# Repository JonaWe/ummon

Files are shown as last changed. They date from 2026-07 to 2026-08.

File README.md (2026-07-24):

# ummon

ummon (from German *Umgebungsmonitor*, "environment monitor") is an ESP32-C6 based environmental sensor board with USB-C power. It reads several environmental sensors over I²C and drives an e-paper display (a 7.5" Waveshare panel in this build). The board is a custom 4-layer PCB designed in KiCad, powered from USB-C with on-board 3.3 V regulation.

## Features

- MCU: ESP32-C6-WROOM-1 (Wi-Fi 6, Bluetooth LE, Zigbee/Thread)
- Sensors over I²C:
  - SHT41 for temperature and humidity
  - SCD41 for CO₂
  - SGP41 for VOC / air quality
- Display: e-paper via an on-board boost converter for the panel supply rails (7.5" Waveshare V2 used here)
- Power: USB-C input, AMS1117 3.3 V LDO, TVS/ESD protection on VBUS and the USB data lines

## Repository structure

```
├── hardware/      KiCad project (schematic, PCB, footprints, datasheets)
├── firmware/      ESP32-C6 firmware (planned)
└── mechanical/    3D-printed enclosure (planned)
```

## Hardware

The PCB uses a 4-layer stackup:

| Layer | Purpose |
|---|---|
| Top | Signals + components |
| Inner 1 | Continuous GND plane |
| Inner 2 | 3.3 V plane |
| Bottom  | Signals |

## Status

- [x] Schematic
- [x] PCB layout
- [ ] Firmware
- [ ] Enclosure

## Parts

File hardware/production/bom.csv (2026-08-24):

Designator | Footprint | Quantity | Value | LCSC Part #
C1, C10, C12, C13, C15, C16, C19, C20, C21, C5, C6, C7, C8 | 0805 | 13 | 100nF | C49678
C14, C17, C18 | 1206 | 3 | 22µF | C12891
C2, C3, C40 | 0805 | 3 | 1µF | C28323
C22 | 1206 | 1 | 4.7μF | C29823
C24, C28, C30, C34, C36 | 0805 | 5 | 1μF/25V | C28323
C26 | 1206 | 1 | 4.7μF/50V | C29823
C27 | 0805 | 1 | 1μF/10V | C28323
C32, C38 | 0805 | 2 | 1μF/50V | C28323
C4, C9 | 0805 | 2 | 10µF | C440198
D2, D3, D4 | SOD-123_L2.8-W1.8-LS3.7-RD | 3 | MBR0530 | C18863
D5 | SOD-123F_L2.8-W1.8-LS3.7-RD | 1 | SMF5.0A | C169426
D6 | SOT-23-6_L2.9-W1.6-P0.95-LS2.8-BL | 1 | USBLC6-2SC6 | C7519
F1 | F1206 | 1 | 1A/24V | C7542957
LED1 | LED-SMD_L1.6-W0.8-R-RD | 1 | KT-0603R | C2286
LED2, LED3 | LED0805-R-RD | 2 | 0805G | C2297
P1 | FPC-SMD_AFC11-S24ICC-00 | 1 | Display | C11075
Q1 | SOT-23-3_L2.9-W1.6-P1.90-LS2.8-BR | 1 | BSS138LT1G | C82045
Q2, Q3 | SOT-23_L2.9-W1.3-P1.90-LS2.4-BR | 2 | AO3401A | C15127
R1 | 0805 | 1 | 4.7Ω | C17675
R10 | 0805 | 1 | 2.2Ω | C17521
R11, R13, R16 | 0805 | 3 | 1Ω | C25271
R12, R15 | 0805 | 2 | 220Ω | C17557
R14 | 0805 | 1 | 1kΩ | C17513
R17, R19 | 0805 | 2 | 100kΩ | C149504
R18, R6, R7 | 0805 | 3 | 4.7kΩ | C17673
R2, R3 | 0805 | 2 | 5.1kΩ | C27834
R4, R5, R8, R9 | 0805 | 4 | 10kΩ | C17414
SW1 | SW-SMD_L3.9-W3.0-P4.45 | 1 | Reboot | C720477
SW2 | SW-SMD_L3.9-W3.0-P4.45 | 1 | Flash | C720477
SW3 | SW-SMD_L3.9-W3.0-P4.45 | 1 | Test Button | C720477
SW4 | SW-SMD_MSK12CO2 | 1 | MINI MSK12CO2 | C2681570
U1 | ESP32-C6-WROOM-1 | 1 | ESP32-C6-WROOM-1-N8 | C5366877
U2 | LGA-20_L10.1-W10.1-P1.25-TL | 1 | SCD41 | C3659294
U3 | DFN-6_L2.4-W2.4-P0.80-TL-EP | 1 | SGP41 | C3659325
U4 | DFN-4_L1.5-W1.5-SHT41-AD1B-R2 | 1 | SHT41 | C7461861
U5 | SOT-223-3_L6.5-W3.4-P2.30-LS7.0-BR | 1 | AMS1117-3.3 | C6186
U6 | IND-SMD_L4.5-W4.0 | 1 | 10μH | C2929419
USB1 | USB-C-SMD_TYPE-C-16PIN-2MD-073 | 1 | TYPE-C 16PIN 2MD | C2765186

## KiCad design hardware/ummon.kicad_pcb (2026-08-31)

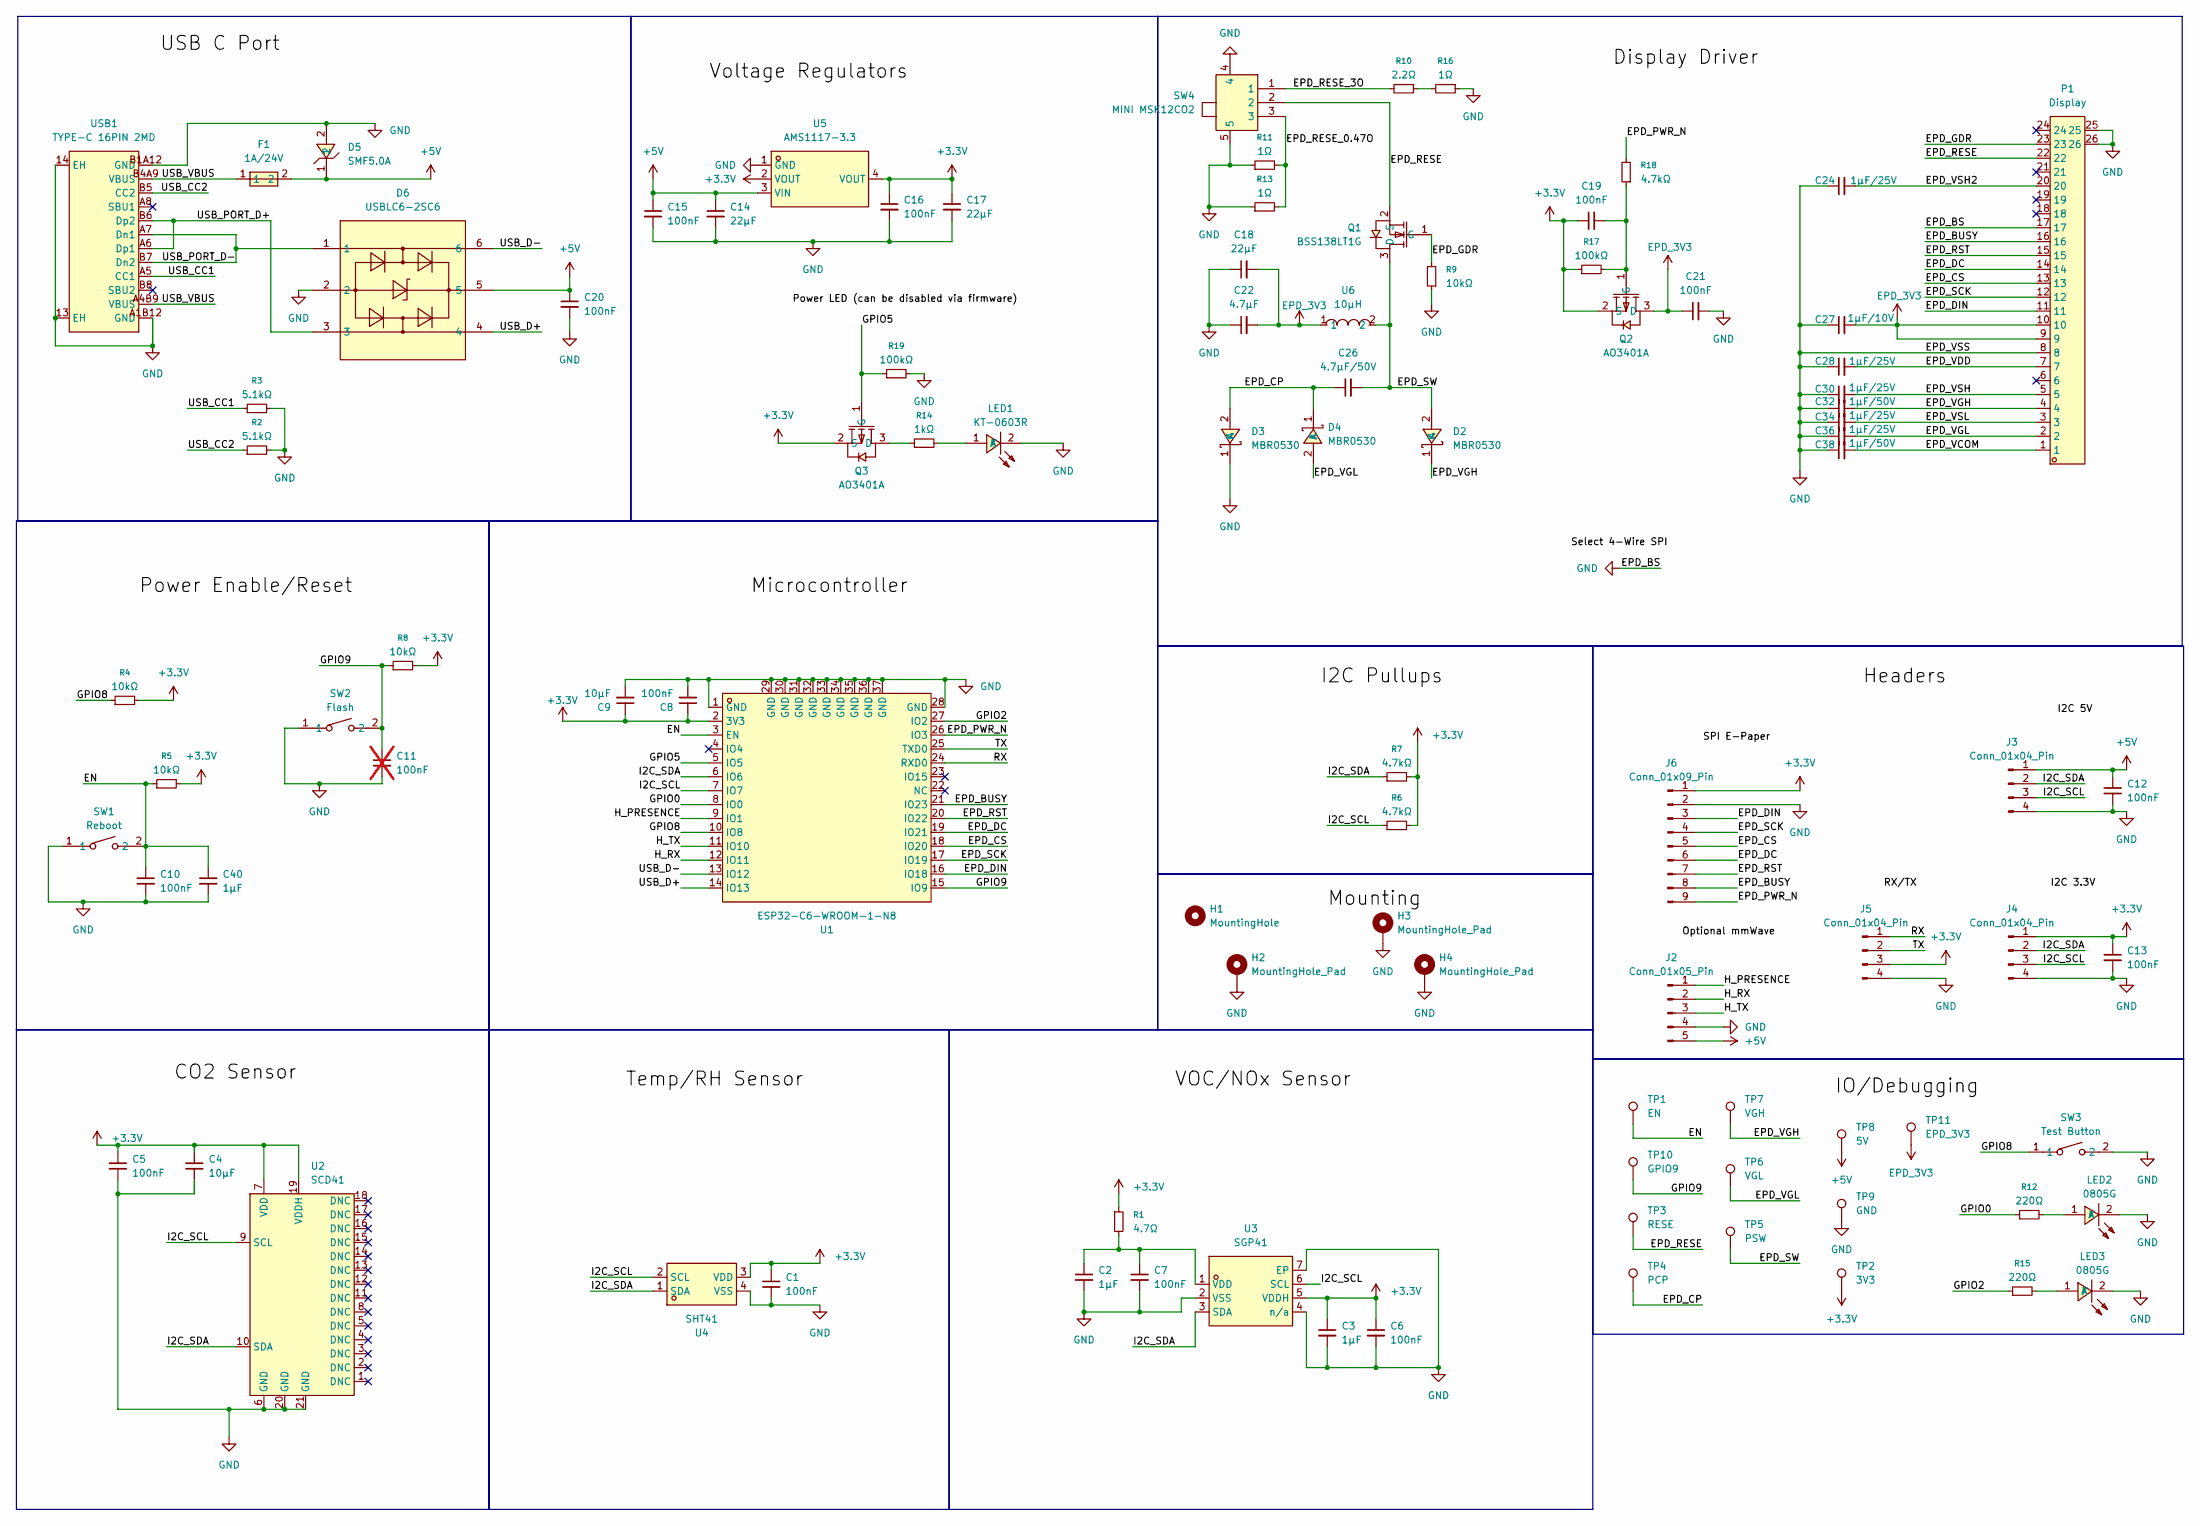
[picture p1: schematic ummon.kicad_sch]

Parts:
C1, C5, C6, C7, C8, C10, C12, C13, C15, C16, C19, C20, C21: 100nF; C_0805_2012Metric; LCSC Part C49678
C2, C3, C40: 1µF; C_0805_2012Metric; LCSC Part C28323
C4, C9: 10µF; C_0805_2012Metric; LCSC Part C440198
C11: 100nF; C_0805_2012Metric; LCSC Part C49678; not fitted
C14, C17, C18: 22µF; C_1206_3216Metric; LCSC Part C12891
C22: 4.7μF; C_1206_3216Metric; LCSC Part C29823
C24, C28, C30, C34, C36: 1μF/25V; C_0805_2012Metric; LCSC Part C28323
C26: 4.7μF/50V; C_1206_3216Metric; LCSC Part C29823
C27: 1μF/10V; C_0805_2012Metric; LCSC Part C28323
C32, C38: 1μF/50V; C_0805_2012Metric; LCSC Part C28323
D2, D3, D4: MBR0530; SOD-123_L2.8-W1.8-LS3.7-RD; MPN LMBR0530T1G; LCSC Part C18863
D5: SMF5.0A; SOD-123F_L2.8-W1.8-LS3.7-RD; MPN SMF5.0A; LCSC Part C169426
D6: USBLC6-2SC6; SOT-23-6_L2.9-W1.6-P0.95-LS2.8-BL; MPN USBLC6-2SC6; LCSC Part C7519
F1: 1A/24V; F1206; MPN 1206L100/24NR; LCSC Part C7542957
H1: MountingHole; MountingHole_3.2mm_M3
H2, H3, H4: MountingHole_Pad; MountingHole_3.2mm_M3_Pad
J2: Conn_01x05_Pin; PinHeader_1x05_P2.54mm_Vertical; LCSC Part C492404
J3, J4, J5: Conn_01x04_Pin; PinHeader_1x04_P2.54mm_Vertical; LCSC Part C2691448
J6: Conn_01x09_Pin; PinHeader_1x09_P2.54mm_Vertical
LED1: KT-0603R; LED-SMD_L1.6-W0.8-R-RD; MPN KT-0603R; LCSC Part C2286
LED2, LED3: 0805G; LED0805-R-RD; MPN KT-0805G; LCSC Part C2297
P1: Display; FPC-SMD_AFC11-S24ICC-00; MPN AFC11-S24ICC-00; LCSC Part C11075
Q1: BSS138LT1G; SOT-23-3_L2.9-W1.6-P1.90-LS2.8-BR; MPN BSS138LT1G; LCSC Part C82045
Q2, Q3: AO3401A; SOT-23_L2.9-W1.3-P1.90-LS2.4-BR; MPN AO3401A; LCSC Part C15127
R1: 4.7Ω; R_0805_2012Metric; LCSC Part C17675
R2, R3: 5.1kΩ; R_0805_2012Metric; LCSC Part C27834
R4, R5, R8, R9: 10kΩ; R_0805_2012Metric; LCSC Part C17414
R6, R7, R18: 4.7kΩ; R_0805_2012Metric; LCSC Part C17673
R10: 2.2Ω; R_0805_2012Metric; LCSC Part C17521
R11, R13, R16: 1Ω; R_0805_2012Metric; LCSC Part C25271
R12, R15: 220Ω; R_0805_2012Metric; LCSC Part C17557
R14: 1kΩ; R_0805_2012Metric; LCSC Part C17513
R17, R19: 100kΩ; R_0805_2012Metric; LCSC Part C149504
SW1: Reboot; SW-SMD_L3.9-W3.0-P4.45; MPN TS-1088-AR02016; LCSC Part C720477
SW2: Flash; SW-SMD_L3.9-W3.0-P4.45; MPN TS-1088-AR02016; LCSC Part C720477
SW3: Test Button; SW-SMD_L3.9-W3.0-P4.45; MPN TS-1088-AR02016; LCSC Part C720477
SW4: MINI MSK12CO2; SW-SMD_MSK12CO2; MPN MINI MSK12CO2; LCSC Part C2681570
TP1: EN; TestPoint_Pad_D1.0mm
TP2: 3V3; TestPoint_Pad_D1.0mm
TP3: RESE; TestPoint_Pad_D1.0mm
TP4: PCP; TestPoint_Pad_D1.0mm
TP5: PSW; TestPoint_Pad_D1.0mm
TP6: VGL; TestPoint_Pad_D1.0mm
TP7: VGH; TestPoint_Pad_D1.0mm
TP8: 5V; TestPoint_Pad_D1.0mm
TP9: GND; TestPoint_Pad_D1.0mm
TP10: GPIO9; TestPoint_Pad_D1.0mm
TP11: EPD_3V3; TestPoint_Pad_D1.0mm
U1: ESP32-C6-WROOM-1-N8; ESP32-C6-WROOM-1; MPN ESP32-C6-WROOM-1-N8; LCSC Part C5366877
U2: SCD41; LGA-20_L10.1-W10.1-P1.25-TL; MPN SCD41-D-R2; LCSC Part C3659294
U3: SGP41; DFN-6_L2.4-W2.4-P0.80-TL-EP; MPN SGP41-D-R4; LCSC Part C3659325
U4: SHT41; DFN-4_L1.5-W1.5-SHT41-AD1B-R2; MPN SHT41-AD1B-R2; LCSC Part C7461861
U5: AMS1117-3.3; SOT-223-3_L6.5-W3.4-P2.30-LS7.0-BR; MPN AMS1117-3.3; LCSC Part C6186
U6: 10μH; IND-SMD_L4.5-W4.0; MPN CY43-10UH; LCSC Part C2929419
USB1: TYPE-C 16PIN 2MD; USB-C-SMD_TYPE-C-16PIN-2MD-073; MPN TYPE-C 16PIN 2MD(073); LCSC Part C2765186

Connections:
+3.3V: C1.1, C3.1, C4.1, C5.1, C6.1, C8.1, C9.1, C13.1, C16.1, C17.1, C19.1, J4.1, J5.3, J6.1, Q2.2 (S), Q3.2 (S), R1.1, R4.2, R5.2, R6.2, R7.2, R8.2, R17.1, TP2.1 (1_1), U1.2 (3V3), U2.7 (VDD), U2.19 (VDDH), U3.5 (VDDH), U4.3 (VDD), U5.2 (VOUT), U5.4 (VOUT)
+5V: C12.1, C14.1, C15.1, C20.1, D5.1, D6.5, F1.2, J2.5, J3.1, TP8.1 (1_1), U5.3 (VIN)
/EN: C10.1, C40.1, R5.1, SW1.2, TP1.1 (1_1), U1.3 (EN)
/EPD_BUSY: J6.8, P1.16, U1.21 (IO23)
/EPD_CP: C26.1, D3.2 (A), D4.1 (K), TP4.1 (1_1)
/EPD_CS: J6.5, P1.13, U1.18 (IO20)
/EPD_DC: J6.6, P1.14, U1.19 (IO21)
/EPD_DIN: J6.3, P1.11, U1.16 (IO18)
/EPD_GDR: P1.23, Q1.1 (G), R9.2
/EPD_PWR_N: J6.9, R18.2, U1.26 (IO3)
/EPD_RESE: P1.22, Q1.2 (S), SW4.2, TP3.1 (1_1)
/EPD_RESE_0.47O: R11.2, R13.2, SW4.3
/EPD_RESE_3O: R10.2, SW4.1
/EPD_RST: J6.7, P1.15, U1.20 (IO22)
/EPD_SCK: J6.4, P1.12, U1.17 (IO19)
/EPD_SW: C26.2, D2.2 (A), Q1.3 (D), TP5.1 (1_1), U6.2
/EPD_VCOM: C38.2, P1.1
/EPD_VDD: C28.2, P1.7
/EPD_VGH: C32.2, D2.1 (K), P1.4, TP7.1 (1_1)
/EPD_VGL: C36.2, D4.2 (A), P1.2, TP6.1 (1_1)
/EPD_VSH: C30.2, P1.5
/EPD_VSH2: C24.2, P1.20
/EPD_VSL: C34.2, P1.3
/GPIO0: R12.1, U1.8 (IO0)
/GPIO2: R15.1, U1.27 (IO2)
/GPIO5: Q3.1 (G), R19.1, U1.5 (IO5)
/GPIO8: R4.1, SW3.1, U1.10 (IO8)
/GPIO9: C11.1, R8.1, SW2.2, TP10.1 (1_1), U1.15 (IO9)
/H_PRESENCE: J2.1, U1.9 (IO1)
/H_RX: J2.2, U1.12 (IO11)
/H_TX: J2.3, U1.11 (IO10)
/I2C_SCL: J3.3, J4.3, R6.1, U1.7 (IO7), U2.9 (SCL), U3.6 (SCL), U4.2 (SCL)
/I2C_SDA: J3.2, J4.2, R7.1, U1.6 (IO6), U2.10 (SDA), U3.3 (SDA), U4.1 (SDA)
/RX: J5.1, U1.24 (RXD0)
/TX: J5.2, U1.25 (TXD0)
/USB_CC1: R3.1, USB1.A5 (CC1)
/USB_CC2: R2.1, USB1.B5 (CC2)
/USB_D+: D6.4, U1.14 (IO13)
/USB_D-: D6.6, U1.13 (IO12)
/USB_PORT_D+: D6.3, USB1.A6 (Dp1), USB1.B6 (Dp2)
/USB_PORT_D-: D6.1, USB1.A7 (Dn1), USB1.B7 (Dn2)
/USB_VBUS: F1.1, USB1.A4B9 (VBUS), USB1.B4A9 (VBUS)
EPD_3V3: C18.2, C21.1, C22.2, C27.2, P1.9, P1.10, Q2.3 (D), TP11.1 (1_1), U6.1
GND: C1.2, C2.2, C3.2, C4.2, C5.2, C6.2, C7.2, C8.2, C9.2, C10.2, C11.2, C12.2, C13.2, C14.2, C15.2, C16.2, C17.2, C18.1, C20.2, C21.2, C22.1, C24.1, C27.1, C28.1, C30.1, C32.1, C34.1, C36.1, C38.1, C40.2, D3.1 (K), D5.2, D6.2, H2.1 (1_1), H3.1 (1_1), H4.1 (1_1), J2.4, J3.4, J4.4, J5.4, J6.2, LED1.2 (K), LED2.2 (K), LED3.2 (K), P1.8, P1.17, P1.25, P1.26, R2.2, R3.2, R9.1, R11.1, R13.1, R16.1, R19.2, SW1.1, SW2.1, SW3.2, SW4.4, SW4.5, TP9.1 (1_1), U1.1 (GND), U1.28 (GND), U1.29 (GND), U1.30 (GND), U1.31 (GND), U1.32 (GND), U1.33 (GND), U1.34 (GND), U1.35 (GND), U1.36 (GND), U1.37 (GND), U2.6 (GND), U2.20 (GND), U2.21 (GND), U3.2 (VSS), U3.4 (n/a), U3.7 (EP), U4.4 (VSS), U5.1 (GND), USB1.13 (EH), USB1.14 (EH), USB1.A1B12 (GND), USB1.B1A12 (GND)
unnamed: LED1.1 (A), R14.2
unnamed: LED2.1 (A), R12.2
unnamed: LED3.1 (A), R15.2
unnamed: C19.2, Q2.1 (G), R17.2, R18.1
unnamed: Q3.3 (D), R14.1
unnamed: R10.1, R16.2
unnamed: C2.1, C7.1, R1.2, U3.1 (VDD)

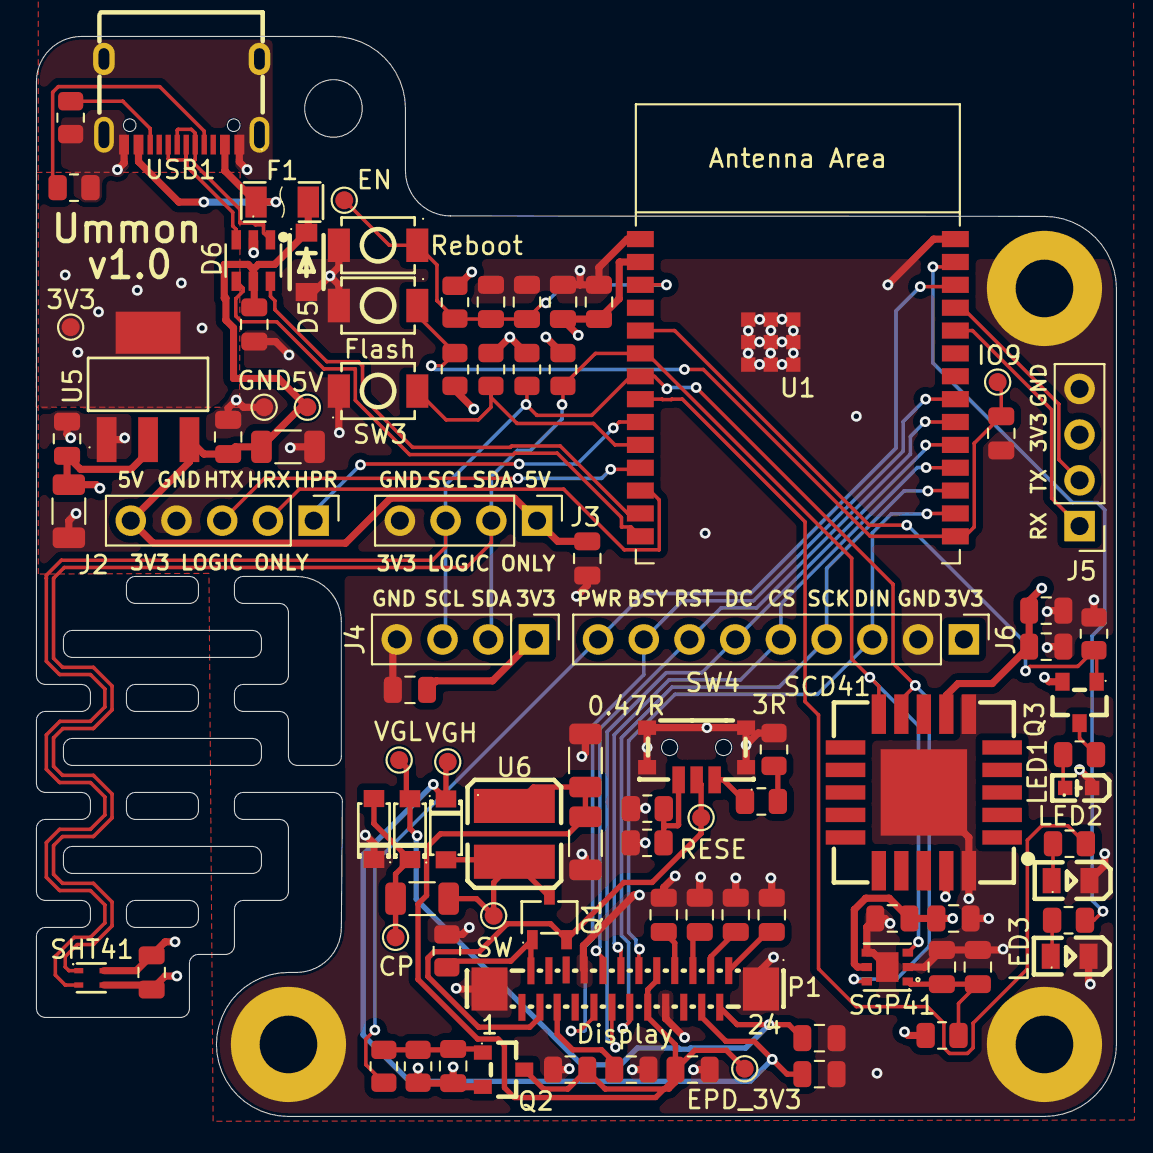
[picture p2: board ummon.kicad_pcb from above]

Board: 4 copper layers, 60.0 x 60.0 mm, 95 parts (0 on the bottom side), 51 nets.

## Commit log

2026-06-22 :tada: Initialize kicad project
    [ummon.kicad_pcb, ummon.kicad_sch]
2026-06-27 :sparkles: Add nix flake to obtain kicad library from jlc
2026-06-27 :sparkles: Initialize kicad project
    [ummon.kicad_sch]
2026-06-27 :sparkles: Add kicad library for sensors and esp32-c6-wroom
2026-06-28 :sparkles: Add reccomended sensor setups
    [ummon.kicad_sch]
2026-06-28 :sparkles: Add microcontroller with boot/reset pins
    [ummon.kicad_sch]
2026-07-02 :sparkles: Add header for spi, i2c and uart
    [ummon.kicad_sch]
2026-07-09 :sparkles: Add voltage regulators
    [ummon.kicad_sch]
2026-07-09 :sparkles: USB is now ESD protected
    [ummon.kicad_sch]
2026-07-09 :sparkles: Add button to lib
2026-07-09 :recycle: Uses correct buttons now
    [ummon.kicad_sch]
2026-07-09 :sparkles: Add required edp driver parts to lib
2026-07-09 :sparkles: Add edp driver
    [ummon.kicad_sch]
2026-07-09 :sparkles: Add smd leds to lib
2026-07-09 :sparkles: Add power indicator leds and gpio led
    [ummon.kicad_sch]
2026-07-09 :sparkles: Add fuse to lib
2026-07-09 :recycle: Replace the generic fuse
    [ummon.kicad_sch]
2026-07-17 :recycle: Remove second ldo and add debug button and led
    [ummon.kicad_sch]
2026-07-18 :sparkles: Add parts for all resistors
    [ummon.kicad_sch]
2026-07-18 :sparkles: Add parts for all capacitors
    [ummon.kicad_sch]
2026-07-18 :bug: Fix footprint for some resistors
    [ummon.kicad_sch]
2026-07-18 :fire: Remove connector pins from BOM
    [ummon.kicad_sch]
2026-07-24 :bug: Fix esd protectoin not being connected on pin2
    [ummon.kicad_sch]
2026-07-24 :sparkles: Add pcb constraints
    [ummon.kicad_pcb]
2026-07-24 :sparkles: Initial placement of components on pcb
    [ummon.kicad_pcb, ummon.kicad_sch]
2026-07-24 :recycle: Propper outline of pcb and rearangement
    [ummon.kicad_pcb]
2026-07-24 :sparkles: Rounding of pcb edges
    [ummon.kicad_pcb]
2026-07-24 :sparkles: Add extra mounting hole for pcb sht41 part
    [ummon.kicad_pcb, ummon.kicad_sch]
2026-07-24 :sparkles: Power routing
    [ummon.kicad_pcb]
2026-07-24 :sparkles: Completes Routing
    [ummon.kicad_pcb]
2026-07-24 :sparkles: ESP via fixes
    [ummon.kicad_pcb]
2026-07-24 :sparkles: Add gnd plane on top layer
    [ummon.kicad_pcb]
2026-07-24 :zap: Differential routing of USB_DATA
    [ummon.kicad_pcb, ummon.kicad_sch]
2026-07-24 :recycle: Adjust fill areas to solid
    [ummon.kicad_pcb]
2026-07-24 :recycle: Change board size to 6x6cm
    [ummon.kicad_pcb, ummon.kicad_sch]
2026-07-24 :sparkles: Fine placement of components and labels
    [ummon.kicad_pcb]
2026-07-24 :sparkles: Completes new routing for new board size
    [ummon.kicad_pcb, ummon.kicad_sch]
2026-07-24 :zap: Fill layer adjustments and impedance routing of usb
    [ummon.kicad_pcb, ummon.kicad_sch]
2026-07-27 :bug: Change usb connector to NPTH
    [ummon.kicad_pcb]
2026-07-27 :recycle: Replace SMBJ6 with SMF5.0 for ESD protection
    [ummon.kicad_sch]
2026-07-27 :recycle: Replace PMS721 with USBLC6 for USB ESD protection
    [ummon.kicad_sch]
2026-07-27 :sparkles: Add various testpoints
    [ummon.kicad_sch]
2026-07-27 :recycle: Change SCD41 paste mask to individual pads
    [ummon.kicad_pcb]
2026-07-27 :construction: WIP buck converter
    [ummon.kicad_sch]
2026-07-31 Revert ":construction: WIP buck converter"
    [ummon.kicad_sch]
2026-07-31 :bug: Fix courtyard for SGP41
    [ummon.kicad_pcb]
2026-07-31 :recycle: Swap USB data lines between USBLC6 channels
    [ummon.kicad_sch]
2026-07-31 :construction: WIP place ESD parts and route epd charge pump
    [ummon.kicad_pcb, ummon.kicad_sch]
2026-07-31 :zap: Adjust I2C routing between header and SHT41
    [ummon.kicad_pcb]
2026-07-31 :zap: Rework EPD routing around display connector
    [ummon.kicad_pcb]
2026-07-31 :construction: WIP name USB port data nets and unplace ldo
    [ummon.kicad_pcb, ummon.kicad_sch]
2026-07-31 :sparkles: Place ldo and route usb frontend
    [ummon.kicad_pcb, ummon.kicad_sch]
2026-08-04 :recycle: Replace RSE solder jumper with MSK12CO2 slide switch
    [ummon.kicad_pcb, ummon.kicad_sch]
2026-08-13 :construction: Place slide switch and rearrange RESE resistors
    [ummon.kicad_pcb]
2026-08-13 :recycle: Name testpoints and move part of 3V3 to inner layer
    [ummon.kicad_pcb, ummon.kicad_sch]
2026-08-13 :construction: WIP reverse display pinout and unplace epd section
    [ummon.kicad_pcb, ummon.kicad_sch]
2026-08-13 :construction: WIP reposition epd section for flipped connector
    [ummon.kicad_pcb]
2026-08-14 :sparkles: Completes routing after connector flip
    [ummon.kicad_pcb, ummon.kicad_sch]
2026-08-15 :construction: WIP refactor driver hat to version 2.3
    [ummon.kicad_sch]
2026-08-17 :sparkles: E-Paper driver board is now reflecting revision 2.3 including the pwr control
    [ummon.kicad_sch]
2026-08-17 :sparkles: Power LED can now be turned off via firmware
    [ummon.kicad_sch]
2026-08-23 :construction: Start of routing for rev 2.3 epd
    [ummon.kicad_pcb, ummon.kicad_sch]
2026-08-23 :sparkles: Completes routing for epd rev 2.3
    [ummon.kicad_pcb, ummon.kicad_sch]
2026-08-24 :bug: Fix usb net names swapped and add 100nF C to D6
    [ummon.kicad_pcb, ummon.kicad_sch]
2026-08-24 :zap: Remove test points and J6 from BOM
    [ummon.kicad_sch]
2026-08-24 :zap: Increase LDO thermal zone size
    [ummon.kicad_pcb]
2026-08-24 :bug: EPD_PWR no longer uses strapping pin 15
    [ummon.kicad_pcb, ummon.kicad_sch]
2026-08-24 :bug: Exclude J* and TP* from position files
    [ummon.kicad_pcb, ummon.kicad_sch]
2026-08-24 :package: Generates production files for jlc
    [bom.csv, designators.csv, positions.csv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]
2026-08-31 :zap: Adjust usb trace width and spacing to 0.2mm
    [ummon.kicad_pcb]
